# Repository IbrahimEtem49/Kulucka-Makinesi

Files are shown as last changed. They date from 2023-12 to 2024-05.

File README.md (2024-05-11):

# Kulucka-Makinesi

Bu projede kullanılan malzemeler;
- DHT22 Nem ve Sıcaklık Sensörü
- DS18B20 Sıcaklık Sensörü
- 16x2 I2C LCD Ekran
- 3 adet Push-buton
- Kırmızı ve Yeşil LED
- Buzzer
- 2 adet fan, biri nem nozülünün ürettiği kabın üzerine konularak üretilen nemi kuluçka makinesine gönderecek.
  Diğeri kuluçka makinesinin havalandırmasını sağlayacak.
  Nem nozülü için konulan fan yalnızca nem nozülü aktif olduğunda çalışmaktadır. Havalandırma fanı ise sürekli aktif.
- 2'li Röle Modülü
- MG996R Servo Motor
- Nem Nozülü
- Isıtıcı (Ampul veya rezistans kullanılabilir)
- XL4016 DC Kıyıcı devresi, giriş olarak eski laptop adaptörü kullanıldı.

(Güncellenecek)

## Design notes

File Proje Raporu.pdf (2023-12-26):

# Kuluçka Otomasyonu Projesi

Projenin Amacı

Kuluçka Otomasyonu projesinin amacı; tavuk, ördek ve bıldırcın gibi çiftlik hayvanlarının yumurtalarının kuluçka sürecini kolay, efektif ve sağlıklı bir biçimde tamamlamasını sağlamak üzere Arduino Uno tabanlı bir otomasyon sisteminin tasarlanması ve uygulanmasıdır.

Projede Kullanılan Malzemeler

DS18B20 Sıcaklık Sensörü

DS18B20 sıcaklık sensörü, 2.5-5.5V arası DC gerilimlerde çalışabilmekte ve -55°C ile +125°C arası sıcaklıkları ±0.4°C doğrulukla ölçebilmektedir. Sensörün hassasiyeti kullanıcı tarafından belirlenebilmekte olup, 0.5°C, 0.25°C, 0.125°C, ve 0.0625°C şeklinde 4 hassasiyet ayarı bulunmaktadır. Bu sensör içerisinde bir termistör bulunur ve sıcaklık değişimine bağlı olarak termistörün direnci değişir. Daha sonra bu direnç değişimi sensör içerisinde yer alan 12 bit Analog-Dijital dönüştürücü kullanılarak dijital veriye dönüştürülür ve sensörün veri aktarım bacağı üzerinden mikro kontrolcüye aktarılır. Projemizde DS18B20 sıcaklık sensörü, kuluçka makinesi içerisindeki sıcaklığı ölçmek için kullanılmıştır.

DHT22 Sıcaklık ve Nem Sensörü

DHT22 sıcaklık ve nem sensörü, 3.3-6V arası DC gerilimlerde çalışabilmekte ve 0-100% arası bağıl nemi ±2% doğrulukla ve 0.1% hassasiyetle, -40°C ile +80°C derece arası sıcaklıkları ±0.5°C doğrulukla ve 0.1°C hassasiyetle ölçebilmektedir. Bu sensör, ortamdaki nemi ölçmek için kapasitif bir nem sensörü, sıcaklığı ölçmek için ise bir termistör kullanır ve veri pinine dijital bir sinyal gönderir. Kapasitif nem sensörü, iki elektrot arasına ince bir metal oksit şeridi yerleştirerek bağıl nemi ölçer. Metal oksidin elektriksel kapasitesi atmosferin bağıl nemine göre değişir. Projemizde DHT22, kuluçka makinesi içerisindeki nemi ölçmek için kullanılmıştır.

Nem Nozülü

Nem nozülü, içerisine konulduğu kaptaki suyu buharlaştırmak için ultrasonik ses dalgaları kullanır. Projemizde nem nozülü kuluçka makinesinin nem seviyesini kontrol etmek için kullanılmıştır.

16x2 I2C LCD Ekran

16x2 LCD (Liquid Crystal Display) ekran, 2 satır ve 16 sütundan oluşur ve aynı anda 32 karakter gösterebilir. Arduino ile bağlantısı 8 pin ile yapılır. Bu istenmeyen bir durumdur çünkü Arduino Uno’daki kullanılabilir pin sayısı oldukça sınırlıdır ve bunların 8 tanesini sadece ekran için ayırmak mantıklı değildir. Bu sebeple genelde I2C modülü ile birlikte kullanılır. Bu modül ekranı çalıştırmak için gerekli pin sayısını 4’e düşürerek pinlerden tasarruf edilmesini sağlar. Projemizde LCD ekran; kalan kuluçka süresi, yumurtaların ne sıklıkla döndürüleceği, sıcaklık ve nem gibi çeşitli parametreleri göstermek amacıyla kullanılacaktır.

MG996R Servo Motor

Servo motorların içerisinde motorun hareketini sağlayan bir DC motor bulunmaktadır. Bu motorun dışında bir dişli mekanizması, potansiyometre ve bir motor sürücü devresi bulunmaktadır. Potansiyometre, motor milinin dönüş miktarını ölçmektedir. Servo içerisindeki DC motor hareket ettikçe potansiyometre döner ve kontrol devresi motorun bulunduğu pozisyon ile istenilen pozisyonu karşılaştırarak motor sürme işlemi yapar. Yani, servolar diğer motorlar gibi harici bir motor sürücüye ihtiyaç duymamaktadırlar. Servolar genellikle 4.8-6V gerilim ile çalışmaktadırlar.

Projemizde kullanılan MG996R Servo Motor, 13 kilograma kadar yükleri çekebilmektedir ve yumurtaların döndürülmesini sağlayan mekanizmaya güç vermek amacıyla kullanılmaktadır.

Buzzer

Buzzer, sesli uyarı amaçlı kullanılan bir devre elemanıdır. Genel olarak piezoelektrik prensibiyle çalışan buzzerlar, yükselticinin içinde yer alan disklere gönderilen titreşimler neticesinde diskte oluşan ses ile çalışmaktadır. Projemizde buzzer, sıcaklık veya nem değerlerinden biri ayarlanan aralığın dışına çıktığında öterek kullanıcıyı uyarmaktadır.

Push Buton

Push buton; normalde yalıtkan durumda olan, basıldığı zaman iletken duruma geçen ve bırakıldığında tekrar yalıtkan duruma geçen devre elemanıdır. Ancak bu durum çeşitli bağlantı senaryoları ile tersine çevrilebilmektedir. Projemizde push buton, LCD ekran üzerinde görüntülenen menü üzerinde gezinmek; sıcaklık, nem, çevirme sıklığı ve kuluçka süresi ayarlarını yapabilmek için gerekli kullanıcı etkileşimini sağlamak amacıyla kullanılmıştır.

Röle

Röle, küçük değerli bir akımın oluşturduğu elektromanyetik alan ile yüksek güçte veya akımda çalışan bir yükü anahtarlayabilmek için bir ya da daha fazla anahtar grubunu kontrol eden devre elemanıdır. Projemizde röle, ısıtıcıyı ve nem nozülünü anahtarlamak için kullanılmıştır.

LED

LED, üzerinden yük geçtiği zaman ışık yayan bir diyot türüdür. Normal bir diyotta olduğu gibi P ve N maddelerinin birleşimi esasına dayanır. LED’e ileri polarma uygulandığı zaman N-tipi bölgedeki elektronlar PN birleşim yüzeyinden geçerek P-tipi maddedeki oyuklarla birleşir. Elektronlar bu oyuklar ile birleşirken açığa çıkan fazla enerji ısı ve ışık şeklinde yayılır. Projemizde, sıcaklık veya nem değerlerinden biri ayarlanan aralığın dışına çıktığında kırmızı led yanarak kullanıcıya bir şeylerin yolunda gitmediğinin sinyalini vermektedir. Her şey yolundaysa da yeşil led yanmaktadır.

Fan

Fanlar, dışarıdan içeri veya içeriden dışarı hava akımı oluşturmak amacıyla kullanılan, merkezinde bir motor ve bu motorun bobinleri ile üzerinde bir pervane bulunan cihazlardır. Projemizde fanlar nem nozülünden çıkan buharı kuluçka makinesi içine üflemek ve hava sirkülasyonu sağlamak amacıyla kullanılmıştır.

Ampul (Isıtıcı)

Akkor flamanlı ampulde elektrik akımı, ısıya dayanıklı ve direnci yüksek bir metal tel üzerinden havası alınmış bir ortamda geçirildiğinde metal tel akkor hâle gelerek ısı üretirken aynı zamanda ışık yayarak çevresini aydınlatır. Bu tel genellikle tungsten metalinden imal edilir. Tungstenin erime sıcaklığı 3.422 °C’dir. Projemizde ampul, kuluçka makinesini ısıtmak için kullanılmıştır.

7805 Voltaj Regülatörü
Voltaj regülatörü, girilen voltaj değerini istenilen çıkış voltaj değerlerine ayarlayan devre elemanlarına verilen isimdir. Projemizde 7805 Voltaj Regülatörü, güç kaynağından gelen 6 veya 12V’luk gerilimi 5V’a düşürmek için kullanılmıştır. Datasheet’inde de önerildiği üzere, sinyaldeki paraziti ve gürültüyü azaltmak amacıyla entegrenin girişine 0.22µF, çıkışına ise 0.1µF’lık kondansatör bağlanmıştır.

Menülerin Kullanımı

LCD ekranda görülebilen 7 farklı interaktif menü bulunmaktadır. Menü seçimi ve menülerden çıkış, “Menu” butonu ile yapılmaktadır. Menülerdeki değerler ise “Yukarı” ve “Aşağı” butonları aracılığıyla ayarlanabilmektedir. Tüm menü seçenekleri ve işlevleri aşağıda verilmiştir:

1. Ana Menü: Bu menüde kalan kuluçka süresi, kuluçka makinesinin anlık sıcaklık ve nem değerleri görülebilmektedir.
2. Sıcaklık Ayarı: Sıcaklık Ayarı menüsünde 0.1℃ hassasiyetle 35-40℃ arasında bir sıcaklık değeri ayarlanabilir.
3. Nem Ayarı: Nem Ayarı menüsünde 0.1% hassasiyetle 40-80%RH arasında bir nem değeri ayarlanabilir.

4. Çevirme Ayarı: Çevirme Ayarı menüsünde yumurtaların kaç saat arayla döndürülecekleri ayarlanabilmektedir. Seçilebilecek değerler 2 ila 8 saat arasında sınırlandırılmıştır.
5. Kuluçka Süresi: Bu menü üzerinden kuluçka süresi, gün cinsinden ayarlanabilmektedir. Seçilebilecek değerler 16 ve 30 arasındadır.
6. EEPROM Kontrol: EEPROM’da; Sıcaklık Ayarı, Nem Ayarı, Çevirme Ayarı ve Kuluçka Süresi menülerinde ayarlanan değerler tutulmaktadır. Bu menü araçılığıyla EEPROM’da kayıtlı değerleri kontrol edilebilir.
7. Reset: EEPROM’da kayıtlı değerleri varsayılan değerler ile değiştirir. Varsayılan değerler sıcaklık için 37.5 ℃, nem için 50%, çevirme sıklığı için 6 saat ve kuluçka süresi için 21 gündür.

Projenin Devre Şeması
Projemizin Fritzing uygulaması üzerinde yapılmış olan devre şeması aşağıda görülmektedir.

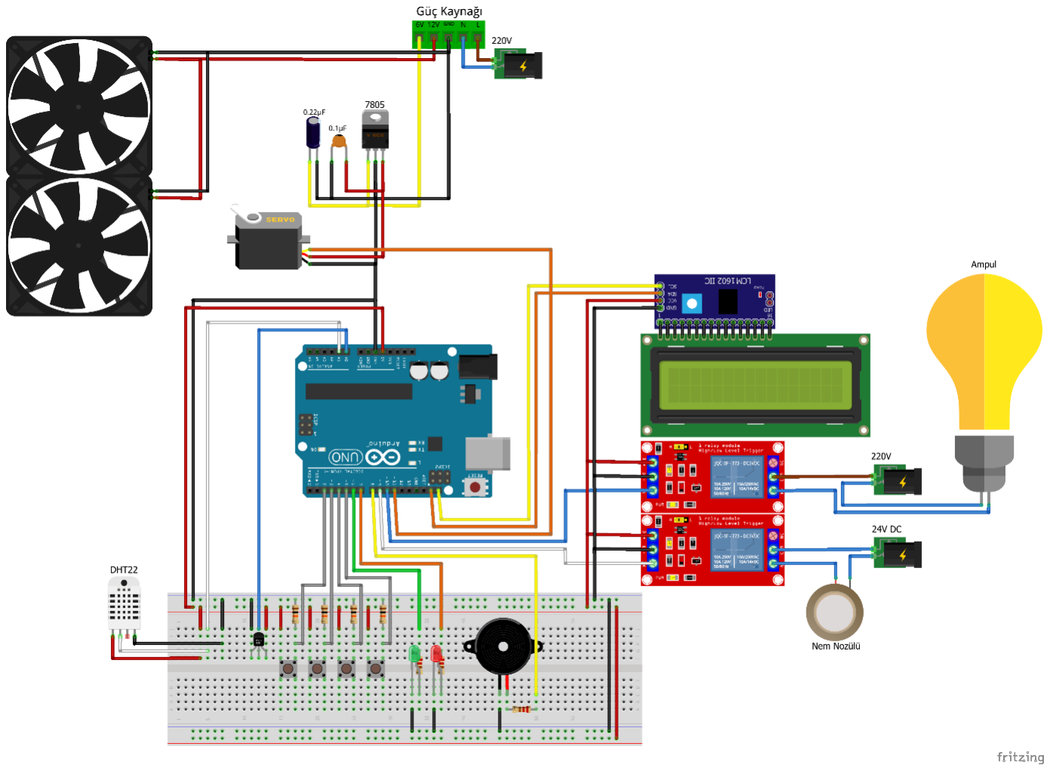
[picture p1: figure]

Proje Kodları

Proje kodlarına;

https://github.com/IbrahimEtem49/Kulucka-Makinesi/blob/main/kulucka_makinesi.ino

linkinden ulaşılabilir.

Kodlarda Kullanılan Kütüphaneler

Projemizdeki donanımları sürmek ve kodlar sadeleştirmek amacıyla çeşitli kütüphaneler kullanılmıştır. Bu kütüphaneler ve görevleri aşağıda verilmiştir:

EEPROM.h: Kodda yer alan EEPROM.get ve EEPROM.put komutları, bu kütüphaneden gelmektedir. Arduino’nun EEPROM belleğine veri yazmak ve okumak amacıyla kullanılmıştır. EEPROM’a yazılan veriler, Arduino’nun gücü kesilse bile silinmez.

Servo.h: Servo motorun kontrolünü sağlamak amacıyla eklenmiştir.

Wire.h: I2C aygıtları ile haberleşmek amacıyla eklenmiştir. Projemizde kullandığımız LCD ekrana bir I2C modülü bağlı olduğundan bu kütüphaneye ihtiyaç duyulmuştur.

LiquidCrystal_I2C.h: LCD ekranın kodlamasını I2C protokolünü kullanarak yapan kütüphane. LCD ekrana veri göndermek için kullanılmaktadır.

OneWire.h: Projede kullanılan DS18B20 sıcaklık sensörüne erişimi sağlayan kütüphanedir. Arduino ile tüm iletişimini tek bir tel üzerinden yaptığı için bu ismi almıştır.

DallasTemperature.h: Dallas firmasının üretmiş olduğu sıcaklık sensörlerini kontrol etmemizi sağlayan kütüphane. DS18B20 sıcaklık sensörünün kontrolünü sağlamak amacıyla eklenmiştir.

DHT.h: DHT22 sensörünün kontrolünü sağlamak amacıyla eklenen kütüphane.

LcdMenu.h: LCD üzerinde kolay ve hızlı bir şekilde menü yapıları oluşturmak amacıyla eklenen kütüphane. (Bkz. https://github.com/forntoh/LcdMenu)

ItemCommand.h: Menü seçeneklerini fonksiyonlara bağlamayı sağlayan, LcdMenu kütüphanesinin alt kütüphanesi.

Projenin Kullanılabileceği Yerler

Projemiz, boyutu dolayısıyla daha çok bireysel kullanıcılara hitap etmektedir. Bu sebeple küçük çiftlik sahipleri, hobi amaçlı kanatlı hayvan yetiştiriciliği yapan kişiler ve kanatlı hayvan yetiştiriciliği sektörüne atılmak isteyen ancak deneyime ihtiyacı olan kişiler tarafından kullanılabilir.

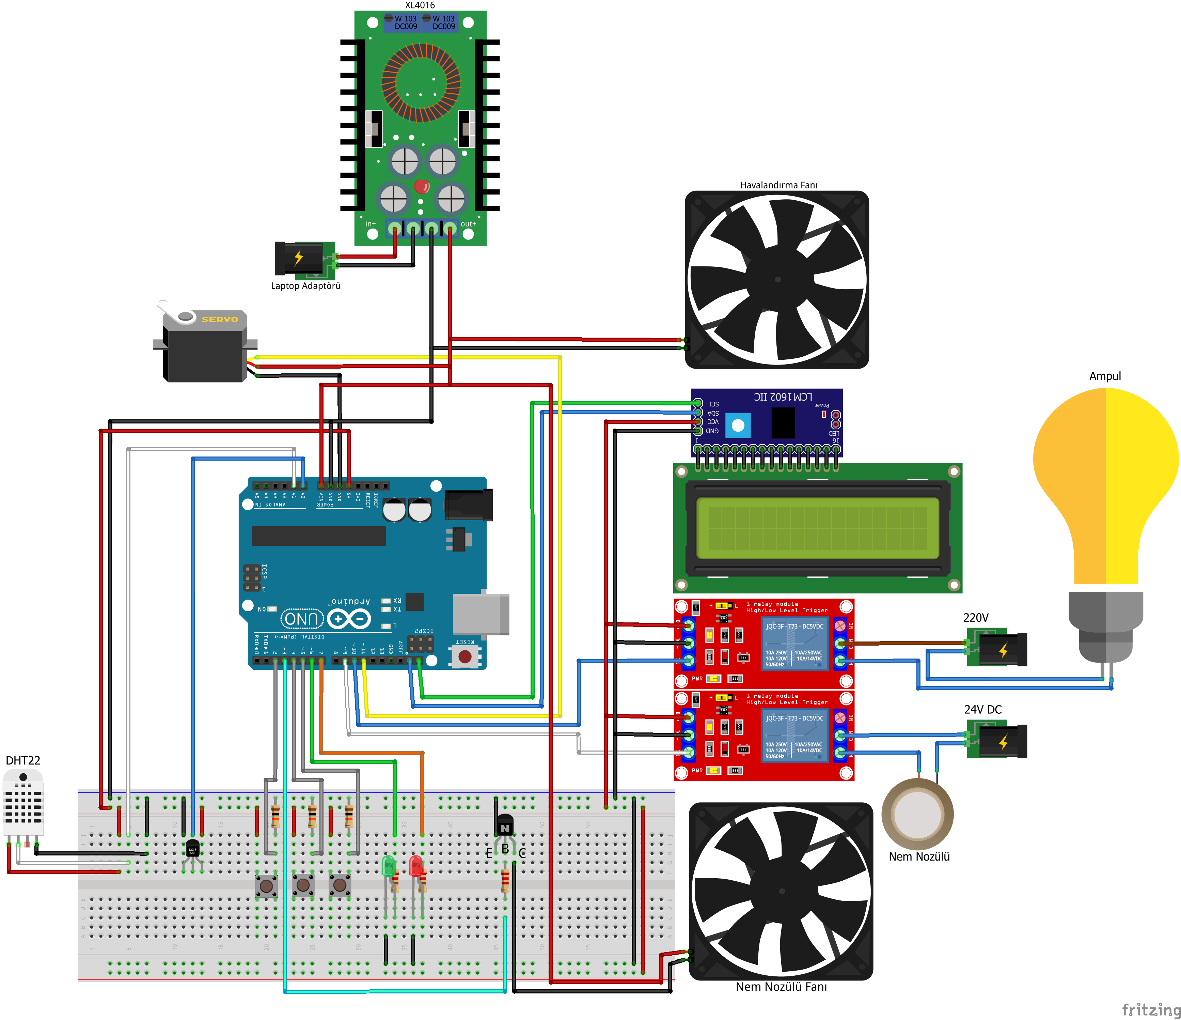
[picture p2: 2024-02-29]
Kulucka_makinesi.png

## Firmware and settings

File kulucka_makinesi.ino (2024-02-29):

#include <EEPROM.h>

#include <Servo.h>
Servo myServo;

#include <Wire.h>
#include <LiquidCrystal_I2C.h>
LiquidCrystal_I2C lcd(0x27, 16, 2);

#include <OneWire.h>
#include <DallasTemperature.h>
#define DSPIN A0
#define ONE_WIRE_BUS DSPIN
OneWire oneWire(ONE_WIRE_BUS);
DallasTemperature sensors(&oneWire);

#include "DHT.h"
#define DHTPIN A1
#define DHTTYPE DHT22
DHT dht(DHTPIN, DHTTYPE);

#include <ItemCommand.h>
#include <ItemSubMenu.h>
#include <LcdMenu.h>

void anaMenu();
void sicaklikAyar();
void nemAyar();
void cevirmeAyar();
void gunAyar();
void eepromKontrol();
void sifirlama();

MAIN_MENU(
  ITEM_COMMAND("Ana Menu", anaMenu),
  ITEM_COMMAND("Sicaklik Ayari", sicaklikAyar),
  ITEM_COMMAND("Nem Ayari", nemAyar),
  ITEM_COMMAND("Cevirme Ayari", cevirmeAyar),
  ITEM_COMMAND("Kulucka Suresi", gunAyar),
  ITEM_COMMAND("EEPROM Kontrol", eepromKontrol),
  ITEM_COMMAND("Reset", sifirlama)
);

LcdMenu menu(2, 16);

const uint8_t bMenu = 2, fan = 3, bYukari = 4, bAsagi = 5, ledG = 6, ledR = 7, buzzer = 8, ampul = 9, nemNozulu = 10;
float sicaklik, nem;

const uint16_t saniye = 1000, dakika = 60000;
const uint32_t saat = 3600000, gun = 86400000, gun21 = 1814400000;
uint32_t sonDonus = 0;
int sayac = 0;

uint32_t sonSicaklikOkuma = 0;
uint32_t sonNemOkuma = 0;

float sicaklikDegeri = 37.5, nemDegeri = 50.0;
uint8_t dondurme = 6, kuluckaSuresi = 21;

uint8_t kayitSicaklik = 100, kayitNem = 120, kayitDonus = 140, kayitKuluckasuresi = 160;

float eepromNem, eepromSicaklik;
uint8_t eepromDonus, eepromKuluckasuresi;

//bool buzzerCalisti = false;

int kalanGun;

#define BUTON_OKUMA(btn, islem) \
  if (digitalRead(btn)) { \
    while (digitalRead(btn)); \
    menu.islem(); \
  }

void setup() {
  EEPROM.begin();
  lcd.init();
  lcd.backlight();
  myServo.attach(11);
  sensors.begin();
  dht.begin();
  pinMode(bMenu, INPUT); pinMode(bYukari, INPUT); pinMode(bAsagi, INPUT);
  pinMode(ledG, OUTPUT); pinMode(ledR, OUTPUT); pinMode(buzzer, OUTPUT); pinMode(ampul, OUTPUT); pinMode(nemNozulu, OUTPUT); pinMode(fan, OUTPUT);
  digitalWrite(ampul, 1);
  digitalWrite(nemNozulu, 0);

  menu.setupLcdWithMenu(0x27, mainMenu);
}

void loop() {
  eepromNem = EEPROM.get(kayitNem, nemDegeri);
  eepromSicaklik = EEPROM.get(kayitSicaklik, sicaklikDegeri);
  eepromDonus = EEPROM.get(kayitDonus, dondurme);
  eepromKuluckasuresi = EEPROM.get(kayitKuluckasuresi, kuluckaSuresi);

  sensors.setResolution(12);
  sicaklikOkuma();
  nemOkuma();

  donus(dondurme);
  sicaklikUyari();
  nemUyari();
  uyari();

  kalanGun = (gun + millis())/gun;
  if (kalanGun > eepromKuluckasuresi){
    kalanGun = 0;
  } 

  BUTON_OKUMA(bAsagi, down)
  BUTON_OKUMA(bYukari, up)
  BUTON_OKUMA(bMenu, enter)
}

void nemOkuma(){
  if (millis() - sonNemOkuma > 1*saniye) {
    nem = dht.readHumidity();
    sonNemOkuma = millis();
  }
}

void sicaklikOkuma(){
  if (millis() - sonSicaklikOkuma > 4*saniye) {
    sensors.requestTemperatures();
    sicaklik = sensors.getTempCByIndex(0);
    sonSicaklikOkuma = millis();
  }
}

void donus(uint32_t donusAralik) {
  if (millis() - sonDonus > donusAralik*saat) {
    myServo.write(30);
    digitalWrite(ledR, 1);
    delay(1500);
    myServo.write(90);
    digitalWrite(ledR, 0);
    sonDonus = millis();
    sayac += 1;
  }
}

bool sicaklikUyari() {
  if (sicaklik < eepromSicaklik) {
    digitalWrite(ampul, 0);
    return 1;
  } else {
    digitalWrite(ampul, 1);
    return 0;
  }
}

bool nemUyari() {
  if (nem < eepromNem) {
    digitalWrite(nemNozulu, 1);
    digitalWrite(fan, 1);
    return 1;
  } else {
    digitalWrite(nemNozulu, 0);
    digitalWrite(fan, 0);
    return 0;
  }
}

void uyari() {
  bool sUyari = sicaklikUyari(), nUyari = nemUyari();
  if ((sUyari == 1) || (nUyari == 1)) {
    digitalWrite(ledR, 1); digitalWrite(ledG, 0);
    /*if (!buzzerCalisti) { 
      tone(buzzer, 1000); 
      delay(2000);
      noTone(buzzer);
      buzzerCalisti = true; 
    }*/
  } else {
    digitalWrite(ledR, 0); digitalWrite(ledG, 1);
    //buzzerCalisti = false; 
  }
}

void anaMenu() {
  lcd.clear();
  while (true) {
    sicaklikOkuma();
    nemOkuma();
    donus(dondurme);
    sicaklikUyari();
    nemUyari();
    uyari();
    lcd.setCursor(0, 0);
    lcd.print("Gun:"); lcd.print(kalanGun); lcd.print("/"); lcd.print(eepromKuluckasuresi); lcd.print(" ");
    lcd.setCursor(0, 1);
    lcd.print(sicaklik); lcd.print((char)223); lcd.print("C|"); lcd.print(nem); lcd.print("%RH");
    if (digitalRead(bMenu)) {
      while(digitalRead(bMenu));
      break;
    }
  }
}

void sicaklikAyar() {
  eepromSicaklik = EEPROM.get(kayitSicaklik, sicaklikDegeri);
  lcd.clear();

  while (true) {
    lcd.home();
    lcd.print("Eski deger:"); lcd.print(eepromSicaklik); lcd.print((char)223); lcd.print("C");
    lcd.setCursor(0,1); 
    lcd.print("Yeni deger:"); lcd.print(sicaklikDegeri); lcd.print((char)223); lcd.print("C");

    if (digitalRead(bYukari)) {
      sicaklikDegeri = constrain(sicaklikDegeri + 0.1, 35.0, 40.0);
      delay(100);
    } else if (digitalRead(bAsagi)) {
      sicaklikDegeri = constrain(sicaklikDegeri - 0.1, 35.0, 40.0);
      delay(100);
    } else if (digitalRead(bMenu)) {
      while(digitalRead(bMenu));
      lcd.clear();
      EEPROM.put(kayitSicaklik, sicaklikDegeri);
      lcd.print("Islem basarili!");

      delay(1000);
      break;
    }
  }
}

void nemAyar() {
  eepromNem = EEPROM.get(kayitNem, nemDegeri);
  lcd.clear();

  while (true) {
    lcd.home();
    lcd.print("Eski deger:"); lcd.print(eepromNem); lcd.print("%RH");
    lcd.setCursor(0,1); 
    lcd.print("Yeni deger:"); lcd.print(nemDegeri); lcd.print("%RH");

    if (digitalRead(bYukari)) {
      nemDegeri = constrain(nemDegeri + 0.1, 40.0, 80.0);
      delay(100);
    } else if (digitalRead(bAsagi)) {
      nemDegeri = constrain(nemDegeri - 0.1, 40.0, 80.0);
      delay(100);
    } else if (digitalRead(bMenu)) {
      while(digitalRead(bMenu));
      lcd.clear();
      EEPROM.put(kayitNem, nemDegeri);
      lcd.print("Islem Basarili!");

      delay(1000);
      break;
    }
  }
}

void cevirmeAyar() {
  eepromDonus = EEPROM.get(kayitDonus, dondurme);
  lcd.clear();

  while (true) {
    lcd.home();
    lcd.print("Eski sure:"); lcd.print(eepromDonus); lcd.print(" saat");
    lcd.setCursor(0,1); 
    lcd.print("Yeni sure:"); lcd.print(dondurme); lcd.print(" saat");

    if (digitalRead(bYukari)) {
      while(digitalRead(bYukari));
      dondurme = constrain(dondurme + 1, 2, 8);
      delay(50);
    } else if (digitalRead(bAsagi)) {
      while(digitalRead(bAsagi));
      dondurme = constrain(dondurme - 1, 2, 8);
      delay(50);
    } else if (digitalRead(bMenu)) {
      while(digitalRead(bMenu));
      lcd.clear();
      EEPROM.put(kayitDonus, dondurme);
      lcd.print("Islem Basarili!");

      delay(1000);
      break;
    }
  }
}

void gunAyar() {
  eepromKuluckasuresi = EEPROM.get(kayitKuluckasuresi, kuluckaSuresi);
  lcd.clear();

  while(true){
    lcd.home();
    lcd.print("Eski sure:"); lcd.print(eepromKuluckasuresi); lcd.print(" gun");
    lcd.setCursor(0,1); 
    lcd.print("Yeni sure:"); lcd.print(kuluckaSuresi); lcd.print(" gun");

    if (digitalRead(bYukari)) {
      while(digitalRead(bYukari));
      kuluckaSuresi = constrain(kuluckaSuresi + 1, 16, 30);
      delay(50);
    } else if (digitalRead(bAsagi)) {
      while(digitalRead(bAsagi));
      kuluckaSuresi = constrain(kuluckaSuresi - 1, 16, 30);
      delay(50);
    } else if (digitalRead(bMenu)) {
      while(digitalRead(bMenu));
      lcd.clear();
      EEPROM.put(kayitKuluckasuresi, kuluckaSuresi);
      lcd.print("Islem Basarili!");

      delay(1000);
      break;
    }
  }
}

void eepromKontrol() {
  lcd.clear();
  
  while (true) {
    lcd.home();
    lcd.print("Sic:"); lcd.print(eepromSicaklik); lcd.print("|Gun:"); lcd.print(eepromKuluckasuresi);
    lcd.setCursor(0,1);
    lcd.print("Nem:"); lcd.print(eepromNem); lcd.print("|Don:"); lcd.print(eepromDonus);
    if (digitalRead(bMenu)) {
      while(digitalRead(bMenu));
      break;
    }
  }
}

void sifirlama() {
  lcd.clear();

  while(true){
    lcd.home();
    lcd.print("Onay icin "); lcd.print("(Up)");
    lcd.setCursor(0,1);
    lcd.print("Red icin  "); lcd.print("(Down)");

    if (digitalRead(bYukari)) {
      while(digitalRead(bYukari));
      EEPROM.put(kayitNem, 50.00);
      EEPROM.put(kayitSicaklik, 37.50);
      EEPROM.put(kayitDonus, 6);
      EEPROM.put(kayitKuluckasuresi, 21);

      lcd.clear(); lcd.home();
      lcd.print("Islem basarili!");

      delay(1000);
      break;
    } else if (digitalRead(bAsagi)) {
      while(digitalRead(bAsagi));

      lcd.clear(); lcd.home();
      lcd.print("Islem iptal");
      lcd.setCursor(0,1);
      lcd.print("edildi!");
      
      delay(1000);
      break;
    } else if (digitalRead(bMenu)) {
      while(digitalRead(bMenu));
      break;
    }
  }
}
